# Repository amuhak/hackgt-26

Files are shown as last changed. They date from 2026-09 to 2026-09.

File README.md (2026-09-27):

# hackgt-26

Mesh of ESP32 sensor buoys. Each buoy logs readings, and the buoys gossip every node's data between themselves. An ESP32 plugged into a laptop can pull the whole fleet's data from any one buoy it reaches.

## Wiring

Text version with pin table: [docs/wiring.md](docs/wiring.md)

Buoy wiring

## Firmware

Requires PlatformIO (`pip install platformio pyserial`).

| Env | Flash to | Purpose |
|---|---|---|
| `buoy` | each buoy | real sensors |
| `buoy_demo` | each buoy | real sensors, one reading every 2 s instead of 30 s, for a live demo |
| `buoy_debug` | a buoy on the bench | real sensors, logs everything at 115200: raw GPS NMEA, every sensor each second, every radio frame with RSSI, reset reason |
| `buoy_sim` | spare ESP32s | fake readings, to test the mesh without wiring. `BACKFILL <n>` over serial queues n extra records, for load tests. |
| `collector` | the ESP32 on the laptop | bridges the mesh to USB serial |
| `meshsim` | any one ESP32 | runs virtual buoys + collector over a lossy fake radio and prints PASS/FAIL. Wipes the board's flash. |

```
pio run -e buoy -t upload --upload-port COM5
pio device monitor -p COM5            # boot log, I2C scan, one sample every 30 s; type STAT for counters
```

Or by board number, with the port auto-detected when one board is plugged in (1 = `buoy_demo`, 2 = `collector`, 3 = `buoy_sim`; stop the server first):

```
python tools/flash.py 1 -m            # -m opens the monitor after; --erase wipes stored records and seq first
```

Collect data into SQLite:

```
pio run -e collector -t upload --upload-port COM6
python tools/collector.py COM6 --db buoy.db
```

| Table | Rows | Source |
|---|---|---|
| `readings` | one per buoy sample (every 30 s, or 2 s with `buoy_demo`) | stored and relayed by the mesh; nothing is lost |
| `motion` | 50 per second per buoy: accel (g), gyro (deg/s), orientation quaternion and roll/pitch/yaw | live only, from buoys in direct range of the collector; committed within 0.5 s, for 3D rendering |

The motion axes are the buoy's: x forward, y left, z up. The quaternion `qw qx qy qz` rotates buoy to world. It comes from a Mahony filter over the accelerometer and gyro. Yaw drifts about 0.5 deg/min, because there's no magnetometer.

## Web console (Tideline)

Map of the fleet, a 3D page per buoy (RAY.stl, tilting live, with an acceleration arrow), alerts, and a voice agent.

Needs Python 3.10+ and Node 20.19+.

```
python -m venv .venv
.venv\Scripts\activate          # macOS/Linux: source .venv/bin/activate
pip install -r requirements.txt
cd web && npm install && npm run build && cd ..
python server/app.py --serial COM5      # runs the collector too; open http://localhost:8000
```

- Without `--serial`, it only reads `buoy.db`, so you can run `tools/collector.py` yourself.
- Voice: put `XAI_API_KEY=...` (Grok Voice) and/or `GEMINI_API_KEY=...` (Gemini Live) in `.env` at the repo root; the Grok / Gemini switch in the header picks one. The browser gets a short-lived token from the backend and talks to the provider directly. Use Chrome.
  - Optional: `VOICE_PROVIDER=gemini` (default provider), `GEMINI_LIVE_MODEL` (default `gemini-3.8-live`; `gemini-3.8-live-extended-thinking` works but takes ~20 s per answer), `GEMINI_VOICE`, `XAI_VOICE`.
- No GPS fix indoors: buoys sit on a ring around the map center (dashed dot). Drag them with the pin button on the map; positions and names are saved in `server/fleet.json`.
- `--sim-fleet 8` adds 8 fake buoys around campus for a fuller map (they aren't written to the DB).
- `--coast 500` adds 500 fake buoys off the Georgia coast (the globe button on the map flies there; say "show me the coast fleet"). They never raise alerts, and the voice agent treats them as a demo, not a problem.
- UI dev: `python server/app.py` plus `npm run dev` in `web/` (proxies to :8000).

## How the mesh works

- Every 30 s, each buoy stores a record in flash. A record holds water temperature, air temperature, pressure, GPS position and time, and wave statistics: vertical-accel RMS and peak, plus tilt, from 50 Hz IMU sampling.
- A buoy broadcasts each new reading as soon as it takes it (collector in range: ~13 ms from sample to DB).
- Every ~5 s, each node broadcasts a summary of which records it holds per buoy over ESP-NOW. Neighbors send each other whatever is missing, so every buoy ends up with a copy of every buoy's data.
- A receiver only accepts the next record in sequence. When it spots a gap, it immediately sends a NACK saying "resend from N".
- A receiver skips a gap only once no neighbor it has heard in the last 30 s still holds those records (they were evicted everywhere).
- The collector advertises what the laptop's DB already has, so buoys only send new records. Once the DB commits, the collector's ack spreads through the mesh and buoys delete the delivered data.
- Buoys serve the collector before lagging buoys, since delivered records get deleted anyway.
- Serial lines to the laptop carry a CRC. On a bad or missing line, `collector.py` asks the collector to resend from its last ack.
- While a collector is in direct range, a buoy also broadcasts its raw 50 Hz IMU samples, 16 per frame (~3 frames/s). These are read from the MPU's FIFO, so loop stalls don't drop any. They're never stored or relayed.

Tunables (sample period, channel, long-range mode) and pins are in `include/proto.h`.

- Long-range mode (`MESH_LONG_RANGE`) roughly doubles range, but every node must run the same setting.
- The mesh only runs between ESP32s.
- Flash holds about 35k records (measured). Every buoy keeps a copy of every buoy's data, so that is shared across the fleet: about 4 days with the laptop offline for 3 buoys at 30 s, 29 h for 10 buoys, 6.5 h for 3 buoys at the 2 s demo rate. After that the oldest records are evicted.

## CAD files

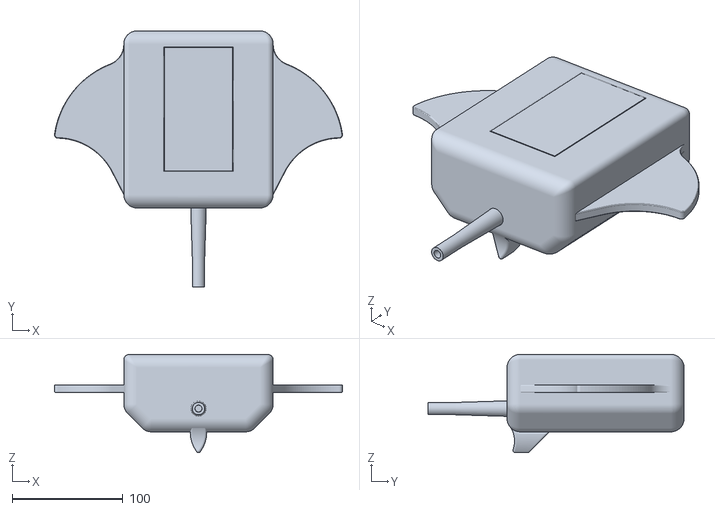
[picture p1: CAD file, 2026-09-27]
web/public/models/ray.stl
260.2 x 231.5 x 88.8

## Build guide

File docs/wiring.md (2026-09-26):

# Buoy node wiring

The same wiring is drawn in [wiring.svg](wiring.svg). The ESP32 pin names below match the board silkscreen; where each pin sits physically varies by board.

```
                      ESP32 DevKit
                   +----------------+
   3V3 rail  <-----| 3V3            |
   GND rail  <-----| GND            |
   5V (GPS)  <-----| VIN            |
   I2C SDA   <---->| GPIO21         |
   I2C SCL   <-----| GPIO22         |
   1-Wire    <---->| GPIO4          |
   GPS TX    ----->| GPIO16 (RX2)   |
   GPS RX    <-----| GPIO17 (TX2)   |
                   +----------------+

 BMP280 (3.3V)           MPU6050                  DS18B20 probe             NEO-6M GPS
 VCC -> 3V3              VCC -> 3V3               red    VDD -> 3V3         VCC -> VIN (5V)
 GND -> GND              GND -> GND               black  GND -> GND         GND -> GND
 SCL -> GPIO22           SCL -> GPIO22            yellow DQ  -> GPIO4       TX  -> GPIO16
 SDA -> GPIO21           SDA -> GPIO21                                      RX  -> GPIO17
 SDO -> GND   (0x76)     AD0 -> GND   (0x68)      4.7 kΩ pull-up:
 CSB -> 3V3   (if pin    INT, XDA, XCL:             3V3 ---[4.7k]---+
               exists)      not connected                           |
                                                    GPIO4 ----------+---- DQ (yellow)
```

| Sensor pin | ESP32 pin | Notes |
|---|---|---|
| BMP280 VCC / GND | 3V3 / GND | 3.3V only, not 5V tolerant |
| BMP280 SCL / SDA | GPIO22 / GPIO21 | shared I2C bus |
| BMP280 SDO | GND | sets I2C addr 0x76 |
| BMP280 CSB | 3V3 | only if the pin is broken out; forces I2C mode |
| MPU6050 VCC / GND | 3V3 / GND | |
| MPU6050 SCL / SDA | GPIO22 / GPIO21 | shared I2C bus |
| MPU6050 AD0 | GND | sets I2C addr 0x68 |
| MPU6050 INT, XDA, XCL | — | leave unconnected (XDA/XCL is an aux bus for extra sensors) |
| DS18B20 VDD (red) / GND (black) | 3V3 / GND | |
| DS18B20 DQ (yellow) | GPIO4 | **4.7 kΩ resistor from DQ to 3V3** |
| NEO-6M VCC / GND | VIN (5V) / GND | module has its own regulator; TX output is 3.3V-safe |
| NEO-6M TX | GPIO16 (RX2) | TX/RX cross over |
| NEO-6M RX | GPIO17 (TX2) | 9600 baud |

- WROVER boards use GPIO16/17 for PSRAM. On one of those, wire the GPS to GPIO25/26 and update `PIN_GPS_*` in `include/proto.h`.
- VIN only carries 5V when the board is powered over USB or 5V. If you power the buoy from a 3.3V source, run the GPS from 3V3 instead.
- Once the firmware is flashed, the boot log runs an I2C scan and should report `0x68 0x76`.

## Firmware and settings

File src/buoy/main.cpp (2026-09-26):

// Buoy: samples sensors, stores readings, and gossips everyone's data.
#include <Arduino.h>

#include "../common/mesh.h"
#include "sensors.h"
#include "store.h"

#ifdef DEBUG_LOG
#define STAT_EVERY_MS 10000UL
#else
#define STAT_EVERY_MS 60000UL
#endif

static Store store;
static Mesh* mesh;
static uint32_t lastSampleAt = 0;
static uint32_t lastStatusAt = 0;
static uint32_t loopCount = 0, loopMaxMs = 0, loopStartedAt = 0;
static char line[32];
static size_t lineLen = 0;
#ifdef SIM_SENSORS
static uint32_t backfillLeft = 0, backfillTotal = 0, backfillStartedAt = 0;
#endif

// One machine-readable line for soak tests: uptime, heap (leaks), radio counters.
static void printStat() {
  const espnow::Stats& rs = espnow::stats();
  const Mesh::Counters& mc = mesh->counters;
  Serial.printf(
      "STAT up=%lu heap=%u minheap=%u rx=%lu rxdrop=%lu tx=%lu txfail=%lu data=%lu nack=%lu heard=%lu readusmax=%lu "
      "writeusmax=%lu loops=%lu loopmaxms=%lu\n",
      millis() / 1000, ESP.getFreeHeap(), ESP.getMinFreeHeap(), (unsigned long)rs.rxFrames,
      (unsigned long)rs.rxDropped, (unsigned long)rs.txFrames, (unsigned long)rs.txFailed, (unsigned long)mc.dataSent,
      (unsigned long)mc.nacksSent, (unsigned long)mc.dataHeard, (unsigned long)mc.readUsMax, (unsigned long)store.writeUsMax, (unsigned long)loopCount,
      (unsigned long)loopMaxMs);
  loopCount = loopMaxMs = 0;  // per-window
  mesh->counters.readUsMax = 0;
  store.writeUsMax = 0;
  store.printStatus(Serial);
}

// Serial commands: STAT, and on simulated buoys BACKFILL <n> to generate load.
static void handleLine(const char* s) {
  if (!strcmp(s, "STAT")) printStat();
#ifdef SIM_SENSORS
  unsigned long n;
  if (sscanf(s, "BACKFILL %lu", &n) == 1) {
    backfillLeft = backfillTotal = n;
    backfillStartedAt = millis();
  }
#endif
}

static void pollSerial() {
  while (Serial.available()) {
    char c = Serial.read();
    if (c == '\n' || c == '\r') {
      if (lineLen) {
        line[lineLen] = 0;
        handleLine(line);
        lineLen = 0;
      }
    } else if (lineLen < sizeof(line) - 1) {
      line[lineLen++] = c;
    }
  }
}

#ifdef SIM_SENSORS
// Appends a slice of synthetic records per loop so the mesh keeps running.
static void backfillStep() {
  if (!backfillLeft) return;
  Record batch[64] = {};
  size_t n = min<uint32_t>(backfillLeft, 64);
  for (size_t i = 0; i < n; i++) {
    batch[i].uptime_s = millis() / 1000;
    batch[i].flags = F_SIM;
  }
  if (!store.appendOwn(batch, n)) {
    Serial.println("BACKFILL failed");
    backfillLeft = 0;
    return;
  }
  backfillLeft -= n;
  if (!backfillLeft) {
    Serial.printf("BACKFILL done n=%lu ms=%lu next=%lu\n", (unsigned long)backfillTotal,
                  millis() - backfillStartedAt, (unsigned long)(batch[n - 1].seq + 1));
  }
}
#endif

static void logRecord(const Record& r) {
  Serial.printf(
      "sample #%lu: water %.2fC air %.2fC %.1fhPa | waves rms %umg peak %umg pitch %.1f roll %.1f | "
      "gps %s %.6f,%.6f sats %u t=%lu (%lu bytes rx) | flags 0x%02x\n",
      (unsigned long)r.seq, r.water_cC / 100.0, r.air_cC / 100.0, r.pressure_pa / 100.0, r.acc_rms_mg,
      r.acc_peak_mg, r.pitch_cdeg / 100.0, r.roll_cdeg / 100.0, (r.flags & F_GPS_FIX) ? "fix" : "nofix",
      r.lat_e7 / 1e7, r.lon_e7 / 1e7, r.sats, (unsigned long)r.gps_time, (unsigned long)sensors::gpsChars(), r.flags);
}

static const char* resetReason() {
  switch (esp_reset_reason()) {
    case ESP_RST_POWERON: return "power-on";
    case ESP_RST_EXT: return "reset pin";
    case ESP_RST_SW: return "software";
    case ESP_RST_PANIC: return "CRASH (panic)";
    case ESP_RST_INT_WDT: return "CRASH (interrupt watchdog)";
    case ESP_RST_TASK_WDT: return "CRASH (task watchdog)";
    case ESP_RST_WDT: return "CRASH (watchdog)";
    case ESP_RST_BROWNOUT: return "BROWNOUT (supply voltage sagged)";
    case ESP_RST_DEEPSLEEP: return "deep sleep wake";
    default: return "unknown";
  }
}

void setup() {
#ifdef DEBUG_LOG
  Serial.setTxBufferSize(16384);  // bursts of frame logs shouldn't stall the loop
#endif
  Serial.begin(115200);
  delay(200);
  uint32_t id = selfId();
  Serial.printf("\nbuoy %08lx booting (reset reason: %s)\n", (unsigned long)id, resetReason());
#ifdef DEBUG_LOG
  Serial.printf("debug build: chip rev %d, %lu MHz, flash %lu KB, heap %u, sdk %s\n", ESP.getChipRevision(),
                (unsigned long)ESP.getCpuFreqMHz(), (unsigned long)(ESP.getFlashChipSize() / 1024),
                ESP.getFreeHeap(), ESP.getSdkVersion());
  Serial.printf("pins: I2C SDA=%d SCL=%d, 1-Wire=%d, GPS RX=%d TX=%d\n", PIN_I2C_SDA, PIN_I2C_SCL, PIN_ONEWIRE,
                PIN_GPS_RX, PIN_GPS_TX);
#endif

  store.begin(id);
  sensors::begin();
  if (!espnow::begin()) Serial.println("mesh: DISABLED");
  mesh = new Mesh(&store, id, espnow::radio());
  store.printStatus(Serial);
  lastSampleAt = millis();
}

void loop() {
  uint32_t loopNow = millis();
  if (loopStartedAt) loopMaxMs = max(loopMaxMs, loopNow - loopStartedAt);
  loopStartedAt = loopNow;
  loopCount++;
  pollSerial();
#ifdef SIM_SENSORS
  backfillStep();
#endif
  sensors::poll();
  static MotionMsg motion;
  size_t motionN;
  if (sensors::takeMotion(motion, motionN) && mesh->sinkNearby(millis())) mesh->sendMotion(motion, motionN);
  espnow::poll(*mesh);
  mesh->loop(millis());

  uint32_t now = millis();
  if (now - lastSampleAt >= SAMPLE_PERIOD_MS) {
    lastSampleAt = now;
    Record r = {};
    sensors::fill(r);
    if (store.appendOwn(&r)) {
      mesh->push(r);
      logRecord(r);
    } else {
      Serial.println("store: append FAILED");
    }
  }
  if (now - lastStatusAt >= STAT_EVERY_MS) {
    lastStatusAt = now;
    printStat();
  }
#ifdef DEBUG_LOG
  static uint32_t lastTickAt = 0;
  if (now - lastTickAt >= 1000) {
    lastTickAt = now;
    sensors::debugTick();
  }
  uint32_t took = millis() - loopNow;
  if (took > 100) Serial.printf("dbg slow loop: %lu ms\n", (unsigned long)took);
#endif
}

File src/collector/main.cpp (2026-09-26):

// Collector: an ESP32 on the laptop's USB port, bridging the mesh to serial.
//
// Serial protocol (921600 baud, newline-terminated):
//   -> laptop  READY <self hex>               until START is received
//   -> laptop  REC <84 hex chars> <crc32 hex> one raw Record, CRC-32 (zlib) of its bytes
//   -> laptop  MOT <hex> <crc32 hex>        one raw MotionMsg (live IMU samples from a buoy in range)
//   -> laptop  LOG <text>
//   <- laptop  HAVE <origin hex> <next>       laptop already has seq < next
//   <- laptop  START                          begin advertising
//   <- laptop  ACK <origin hex> <next>        committed to the DB; buoys may prune
//   <- laptop  REWIND                         a REC line was lost: resend from the last ACKs
#include <Arduino.h>

#include "../common/mesh.h"
#include "../common/sink.h"

static uint32_t crc32(const uint8_t* p, size_t n) {
  uint32_t c = 0xFFFFFFFF;
  while (n--) {
    c ^= *p++;
    for (int k = 0; k < 8; k++) c = (c >> 1) ^ (0xEDB88320 & -(c & 1));
  }
  return ~c;
}

static void emit(const Record& r) {
  Serial.print("REC ");
  const uint8_t* b = reinterpret_cast<const uint8_t*>(&r);
  for (size_t k = 0; k < sizeof(Record); k++) Serial.printf("%02x", b[k]);
  Serial.printf(" %08lx\n", (unsigned long)crc32(b, sizeof(Record)));
}

static void emitMotion(const MotionMsg& m, size_t n) {
  Serial.print("MOT ");
  const uint8_t* b = reinterpret_cast<const uint8_t*>(&m);
  size_t len = offsetof(MotionMsg, s) + n * sizeof(MotionSample);
  for (size_t k = 0; k < len; k++) Serial.printf("%02x", b[k]);
  Serial.printf(" %08lx\n", (unsigned long)crc32(b, len));
}

static CollectorSink sink(emit, emitMotion);
static Mesh* mesh;
static uint32_t id;
static char line[64];
static size_t lineLen = 0;
static uint32_t lastReadyAt = 0;
static uint32_t lastStatAt = 0;

static void handleLine(char* s) {
  char cmd[8];
  char originHex[12];
  unsigned long next;
  if (sscanf(s, "%7s %11s %lu", cmd, originHex, &next) == 3) {
    uint32_t origin = strtoul(originHex, nullptr, 16);
    if (!strcmp(cmd, "HAVE")) sink.have(origin, next);
    else if (!strcmp(cmd, "ACK")) sink.ack(origin, next);
  } else if (!strcmp(s, "REWIND")) {
    sink.rewind();
    Serial.println("LOG rewound to last ACKs");
  } else if (!strcmp(s, "START")) {
    sink.started = true;
    Serial.println("LOG started");
  }
}

void setup() {
  Serial.setTxBufferSize(8192);
  Serial.setRxBufferSize(4096);
  Serial.begin(921600);
  id = selfId();
  if (!espnow::begin()) Serial.println("LOG mesh init FAILED");
  mesh = new Mesh(&sink, id, espnow::radio());
}

void loop() {
  while (Serial.available()) {
    char c = Serial.read();
    if (c == '\n' || c == '\r') {
      if (lineLen > 0) {
        line[lineLen] = 0;
        handleLine(line);
        lineLen = 0;
      }
    } else if (lineLen < sizeof(line) - 1) {
      line[lineLen++] = c;
    }
  }

  if (!sink.started && millis() - lastReadyAt >= 1000) {
    lastReadyAt = millis();
    Serial.printf("READY %08lx\n", (unsigned long)id);
  }
  espnow::poll(*mesh);
  mesh->loop(millis());

  if (millis() - lastStatAt >= 60000) {
    lastStatAt = millis();
    const espnow::Stats& rs = espnow::stats();
    Serial.printf("LOG STAT up=%lu heap=%u minheap=%u rx=%lu rxdrop=%lu tx=%lu txfail=%lu nack=%lu heard=%lu\n",
                  millis() / 1000, ESP.getFreeHeap(), ESP.getMinFreeHeap(), (unsigned long)rs.rxFrames,
                  (unsigned long)rs.rxDropped, (unsigned long)rs.txFrames, (unsigned long)rs.txFailed,
                  (unsigned long)mesh->counters.nacksSent, (unsigned long)mesh->counters.dataHeard);
  }
}

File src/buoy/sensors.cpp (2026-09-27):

#include "sensors.h"

#include <Arduino.h>
#include <math.h>

#include "../common/mesh.h"

#ifndef SIM_SENSORS
#include <Adafruit_BMP280.h>
#include <DallasTemperature.h>
#include <OneWire.h>
#include <TinyGPSPlus.h>
#include <Wire.h>
#endif

namespace sensors {
namespace {

constexpr float kG = 9.80665f;

// Wave statistics for the current period. Gravity is tracked with a slow
// low-pass filter so the vertical component survives any buoy tilt.
struct Waves {
  float g[3] = {0, 0, kG};
  bool seeded = false;
  float sum[3] = {0, 0, 0};
  double sumSq = 0;
  float peak = 0;
  uint32_t n = 0;

  void add(float ax, float ay, float az) {
    if (!seeded) {
      g[0] = ax, g[1] = ay, g[2] = az;
      seeded = true;
    }
    g[0] += 0.02f * (ax - g[0]);
    g[1] += 0.02f * (ay - g[1]);
    g[2] += 0.02f * (az - g[2]);
    float gm = sqrtf(g[0] * g[0] + g[1] * g[1] + g[2] * g[2]);
    if (gm < 1e-3f) return;
    float vert = (ax * g[0] + ay * g[1] + az * g[2]) / gm - gm;
    sum[0] += ax, sum[1] += ay, sum[2] += az;
    sumSq += vert * vert;
    peak = max(peak, fabsf(vert));
    n++;
  }

  void fill(Record& r) {
    if (n > 0) {
      float mx = sum[0] / n, my = sum[1] / n, mz = sum[2] / n;
      r.acc_rms_mg = min(65535.0, sqrt(sumSq / n) / kG * 1000.0);
      r.acc_peak_mg = min(65535.0f, peak / kG * 1000.0f);
      r.pitch_cdeg = atan2f(-mx, sqrtf(my * my + mz * mz)) * 18000.0f / PI;
      r.roll_cdeg = atan2f(my, mz) * 18000.0f / PI;
    }
    sum[0] = sum[1] = sum[2] = 0;
    sumSq = 0;
    peak = 0;
    n = 0;
  }
};

Waves waves;
uint32_t lastImuAt = 0;

// Live motion: 50 Hz samples batched into MotionMsg frames for the collector.
MotionMsg motionBuf, motionOut;
size_t motionN = 0;
bool motionReady = false;
uint32_t imuIndex = 0;  // sample number on a 50 Hz grid, so the laptop sees gaps

void addMotion(const int16_t a[3], const int16_t g[3]) {
  if (motionN == 0) {
    motionBuf.t0_ms = imuIndex * IMU_SAMPLE_MS;
    motionBuf.period_ms = IMU_SAMPLE_MS;
  }
  motionBuf.s[motionN++] = {a[0], a[1], a[2], g[0], g[1], g[2]};
  imuIndex++;
  if (motionN == MOTION_SAMPLES) {
    motionOut = motionBuf;
    motionReady = true;
    motionN = 0;
  }
}

int16_t clamp16(float v) { return (int16_t)constrain(lroundf(v), -32768L, 32767L); }

#ifdef SIM_SENSORS

float noise(float amp) { return amp * ((int32_t)(esp_random() % 2001) - 1000) / 1000.0f; }

// A buoy rocking in a swell: roll 10 deg over 4 s, pitch 6 deg over 6.5 s,
// 1.5 m/s2 of heave over 6 s. Gyro rates match the angles, so the laptop's
// orientation filter can be checked against a known answer.
void simImu(uint32_t now) {
  float t = now / 1000.0f;
  float w1 = 2 * PI / 4.0f, w2 = 2 * PI / 6.5f;
  float roll = radians(10.0f) * sinf(w1 * t), pitch = radians(6.0f) * sinf(w2 * t);
  float rollRate = radians(10.0f) * w1 * cosf(w1 * t), pitchRate = radians(6.0f) * w2 * cosf(w2 * t);
  float up = kG + 1.5f * sinf(t * 2 * PI / 6.0f);
  float ax = -up * sinf(pitch) + noise(0.1f);
  float ay = up * sinf(roll) * cosf(pitch) + noise(0.1f);
  float az = up * cosf(roll) * cosf(pitch) + noise(0.1f);
  waves.add(ax, ay, az);
  // Body rates with no yaw: p = roll', q = pitch' cos(roll), r = -pitch' sin(roll).
  float rates[3] = {rollRate, pitchRate * cosf(roll), -pitchRate * sinf(roll)};
  int16_t a[3] = {clamp16(ax / kG * ACCEL_LSB_PER_G), clamp16(ay / kG * ACCEL_LSB_PER_G),
                  clamp16(az / kG * ACCEL_LSB_PER_G)};
  int16_t g[3];
  for (int k = 0; k < 3; k++) g[k] = clamp16(degrees(rates[k]) * GYRO_LSB_PER_DPS);
  imuIndex = now / IMU_SAMPLE_MS;
  addMotion(a, g);
}

#else

Adafruit_BMP280 bmp;
OneWire oneWire(PIN_ONEWIRE);
DallasTemperature ds(&oneWire);
TinyGPSPlus gps;
HardwareSerial gpsSerial(2);
bool bmpOk = false, mpuOk = false;
int gpsRxPin = PIN_GPS_RX;
uint32_t mpuErrors = 0;

#ifdef DEBUG_LOG
// Echoes raw GPS bytes a line at a time; unprintable bytes (wrong baud,
// noise) show as '?'.
char gpsLine[128];  // $PUBX,00 replies run past 100 chars
size_t gpsLen = 0;

void echoGps(char c) {
  if (c == '\r') return;
  if (c != '\n') gpsLine[gpsLen++] = isprint((unsigned char)c) ? c : '?';
  if (c == '\n' || gpsLen == sizeof(gpsLine) - 1) {
    gpsLine[gpsLen] = 0;
    Serial.printf("gps< %s\n", gpsLine);
    gpsLen = 0;
  }
}
#endif

// Days since 1970-01-01 for a proleptic Gregorian date.
int32_t daysFromCivil(int32_t y, uint32_t m, uint32_t d) {
  y -= m <= 2;
  int32_t era = (y >= 0 ? y : y - 399) / 400;
  uint32_t yoe = y - era * 400;
  uint32_t doy = (153 * (m + (m > 2 ? -3 : 9)) + 2) / 5 + d - 1;
  uint32_t doe = yoe * 365 + yoe / 4 - yoe / 100 + doy;
  return era * 146097 + (int32_t)doe - 719468;
}

// Register-level MPU driver. Many boards sold as MPU6050 carry an MPU6500 or
// similar, which shares these registers but fails the Adafruit chip-id check.
uint8_t mpuAddr = 0;

bool mpuWrite(uint8_t reg, uint8_t val) {
  Wire.beginTransmission(mpuAddr);
  Wire.write(reg);
  Wire.write(val);
  return Wire.endTransmission() == 0;
}

bool mpuRead(uint8_t reg, uint8_t* buf, size_t n) {
  Wire.beginTransmission(mpuAddr);
  Wire.write(reg);
  if (Wire.endTransmission(false) != 0) return false;
  if (Wire.requestFrom((int)mpuAddr, (int)n) != (int)n) return false;
  for (size_t i = 0; i < n; i++) buf[i] = Wire.read();
  return true;
}

size_t fifoSize = 512;
int16_t gyroBias[3] = {0, 0, 0};
uint32_t fifoResets = 0;

int16_t be16(const uint8_t* b) { return (int16_t)(b[0] << 8 | b[1]); }
int16_t neg16(int16_t v) { return v == INT16_MIN ? INT16_MAX : -v; }

// Rotates a sensor-axes vector into buoy axes (z up), keeping a right-handed frame.
void toBuoy(const int16_t s[3], int16_t o[3]) {
#if MPU_UP == MPU_UP_PX  // chip on edge, marked face (+Z) toward the bow
  o[0] = s[2], o[1] = neg16(s[1]), o[2] = s[0];
#elif MPU_UP == MPU_UP_NX
  o[0] = s[2], o[1] = s[1], o[2] = neg16(s[0]);
#elif MPU_UP == MPU_UP_PY
  o[0] = s[0], o[1] = neg16(s[2]), o[2] = s[1];
#elif MPU_UP == MPU_UP_NY
  o[0] = s[0], o[1] = s[2], o[2] = neg16(s[1]);
#elif MPU_UP == MPU_UP_NZ
  o[0] = s[0], o[1] = neg16(s[1]), o[2] = neg16(s[2]);
#else
  o[0] = s[0], o[1] = s[1], o[2] = s[2];
#endif
}

void mpuFifoReset() {
  mpuWrite(0x6A, 0x04);  // FIFO_RST
  mpuWrite(0x6A, 0x40);  // FIFO_EN
  imuIndex = millis() / IMU_SAMPLE_MS;  // sample times stay honest across the gap
  motionN = 0;
}
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

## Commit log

2026-09-26 Add buoy wiring diagram
2026-09-26 Add text version of the wiring diagram
2026-09-26 Support MPU6500 clones, probe GPS wiring at boot
    The IMU board reports WHO_AM_I 0x70 (MPU6500), which the Adafruit
    MPU6050 library rejects; read registers directly instead. Log GPS
    bytes received and probe swapped pins/bauds to diagnose wiring.
    [main.cpp, sensors.cpp]
2026-09-26 Fix mesh data loss on dropped frames; add on-device mesh simulation
    A simulated 4-buoy fleet with 20% frame loss showed the collector
    skipping past lost frames, after which the laptop's ack made buoys
    delete the skipped records everywhere. Receivers now accept only
    contiguous records (jumping only when the sender no longer holds the
    gap) and NACK gaps immediately so senders rewind within ~100 ms.
    Mesh is now a class over a Radio interface so the simulation can run
    several nodes on one ESP32.
    [espnow.cpp, main.cpp, proto.h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]
2026-09-26 Soak-test diagnostics: STAT counters, BACKFILL load, resilient collector.py
    - STAT line (buoy, every 60 s or on demand) and LOG STAT (collector):
    heap/min heap, radio rx/drop/tx/fail, mesh data/NACK counts, loop timing
    - BACKFILL <n> serial command on simulated buoys for bandwidth tests
    - Store::appendOwn takes a batch
    - collector.py reconnects after serial errors and announces itself on
    connect even if the ESP32 didn't reset
    [collector.py, espnow.cpp, main.cpp]
2026-09-26 Hold before skipping gaps, serve the collector first, cache segment files, CRC the serial link
    - A receiver skips a gap only after it has looked unfillable for 30 s, so a
    neighbor that still holds the records but hasn't spoken yet (booting) can
    fill it. Seen on hardware; meshsim phase 6 reproduces it (fails without
    the hold).
    - Collector summaries are tagged; buoys serve the collector's position before
    lagging buoys, which were dragging every burst back to their position.
    - Store keeps two segment files open instead of stat+open+close per access.
    - REC lines carry a CRC-32. collector.py stores and acks only contiguous
    records; on a corrupt line or seq jump it sends REWIND and the c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
    [collector.py, main.cpp, proto.h]
2026-09-26 collector.py: wait for the collector's rewind confirmation instead of a time window
    After a REWIND the collector can jump straight past an evicted range and
    stream hundreds of records within the old 2 s window; those were discarded as
    in-flight and then skipped for good (511 records in the soak's eviction test).
    Lines are now discarded only until the collector's 'LOG rewound' line.
    [collector.py]
2026-09-26 Add buoy_debug build: raw GPS echo, per-second sensor dump, per-frame radio log with RSSI
    Also prints the reset reason at boot in every build, so brownouts on battery
    show up.
    [espnow.cpp, main.cpp, sensors.cpp]
2026-09-26 meshsim: live 4-hop chain and one-way-link phases
    Phase 7: A-B-C-D-collector with every buoy sampling; checks delivery, pruning
    at every hop, and A's end-to-end latency (44-57 s max at 20% loss).
    Phase 8: A hears the collector but not vice versa; B must still relay A's
    records even though it overhears A serving the collector (38 s max).
2026-09-26 Push each new reading immediately; add buoy_demo (2 s sampling)
    A buoy broadcasts a reading as soon as it takes it instead of waiting for its
    next summary. On hardware, sample -> DB commit is 13 ms median (56 samples,
    max 339 ms); before, up to one summary interval (5-6 s). meshsim 90/90, 1-hop
    worst case 7-8 s -> 3 s at 20% loss.
    buoy_demo samples every 2 s for a live demo. SAMPLE_PERIOD_MS is overridable.
    Also widens the debug GPS echo buffer for $PUBX lines.
2026-09-26 Rotate MPU axes for its on-edge mounting (MPU_UP, default +X up)
    The MPU stands on edge on the buoy board, so tilt read -88 deg when level.
    MPU_UP maps any of the six axis-up mountings into buoy axes; on #1 pitch/roll
    now read 1.6/-0.2 deg lying flat.
2026-09-26 Stream live 50 Hz IMU (accel + gyro) to the collector for 3D rendering
    Buoys read the MPU FIFO and broadcast 16-sample MOTION frames while a
    collector is in direct range (never stored or relayed). collector.py runs
    a Mahony filter and writes accel, gyro, quaternion and roll/pitch/yaw to a
    new motion table.
2026-09-26 README: flash capacity is ~35k records (measured in the eviction test), not 45k
2026-09-26 README: fix demo-rate capacity figure (6.5 h)
2026-09-27 Add Tideline web console: live fleet map, 3D buoy page, alerts, voice agent
    server/app.py (FastAPI) tails buoy.db, pushes readings, 50 Hz motion and
    alerts over a WebSocket, serves history/summary endpoints, and mints xAI
    realtime tokens. --serial runs the collector; --sim-fleet adds fake buoys.
    web/ (React + MapLibre + three.js, Carbon-style, dark/light): map colored by
    a chosen metric with hover snapshots, a per-buoy page with RAY.stl tilting
    live and a gravity-removed acceleration arrow, and a grok-voice agent that
    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
    [ray.stl]
2026-09-27 Voice agent live: accept GROK key name, terser prompt; MPU face points to the bow
    - server reads the xAI key from XAI_API_KEY, GROK or GROCK in .env
    - voice prompt: no "let me check" preambles, lead with what matters
    - MPU_UP_PX now takes the chip's marked face (+Z) as forward, matching how
    it sits in the RAY hull; the old mapping had pitch and roll sign-flipped
    [proto.h, sensors.cpp]
2026-09-27 Voice agent: box problems on the history chart, hang up on "that's all"
    - show_problem(alert_id) opens the buoy's history for the alert's metric and
    boxes when it happened; outages (silent, sensor lost) are boxed until they
    recovered or now. show_chart boxes any span the agent finds in the data.
    - Clicking an alert in the feed or a toast does the same.
    - History chart: fixed time window, lines break across gaps.
    - end_session: the agent says goodbye and closes the session.
    - Voice panel moves over the 3D stage on buoy pages so charts stay visible.
    - /api/summary reports when the min and max happened.
2026-09-27 Voice agent on Grok or Gemini Live (header switch); phone layout fixes
    - Grok Voice and Gemini 3.8 Live behind one transport interface; tools,
    audio, alerts, chart boxing and end_session are shared. The backend mints a
    short-lived token for either (GEMINI_API_KEY / GOOGLE in .env).
    - Header Grok / Gemini switch, remembered per browser; switching mid-session
    reconnects. VOICE_PROVIDER and GEMINI_LIVE_MODEL set the defaults.
    - Phones: compact title and one-row attitude strip so the 3D model is clear;
    map overview is a bottom sheet with the map fitted above it.
2026-09-27 collector: re-learn gyro bias whenever a buoy sits still (stops yaw drift)
    [collector.py]
2026-09-27 tools/flash.py: flash a board by number, port auto-detected
2026-09-27 Alert on fast water temperature swings; give the voice agent 10-min changes and a plain real/simulated field
2026-09-27 Only show "Relayed via mesh" while a buoy's readings are still arriving
2026-09-27 tools/outages.py: classify a buoy's dropouts as link loss, reboot or freeze
    [outages.py]
2026-09-27 Place mode: pin the base at this computer's location
